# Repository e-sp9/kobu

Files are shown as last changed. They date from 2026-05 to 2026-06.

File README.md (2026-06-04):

# kobu

自作分割キーボード「kobitokey」にインスパイアされて作った派生キーボード「kobu」の KiCad プロジェクトとファームウェアです。親指キーを追加し、メインキー側を 2 キー削っています。

## ディレクトリ構成

| ディレクトリ | 中身 |
|---|---|
| [`pcb/`](pcb/) | KiCad プロジェクト (PCB / 回路図) |
| [`case/`](case/) | ケースの STEP / STL |
| [`firmware/rmk/`](firmware/rmk/) | RMK ベースのファームウェア (Rust, thumbv7em-none-eabihf) |
| [`firmware/zmk/`](firmware/zmk/) | ZMK 版ファームウェア (Zephyr, Nix/flake ビルド) |
| [`web/rmk-editor/`](web/rmk-editor/) | RMK 用 Web キーマップエディタ (WebHID + Vial protocol, React) |
| [`web/zmk-editor/`](web/zmk-editor/) | ZMK 用 Web キーマップエディタ (ZMK Studio over USB/BLE, React) |

## 開発環境

`flake.nix` が toolchain バージョンの単一情報源。CI も同じ devshell で走るので host とドリフトしない。

### direnv ですぐに使う (推奨)

[nix-direnv](https://github.com/nix-community/nix-direnv) を入れていれば `cd` するだけで対応する devshell が自動起動する:

```sh
direnv allow              # 初回のみ
cd ~/git/private/kobu     # → 全部入り devshell (firmware + web)
cd firmware/rmk/              # → firmware-only (Rust + flip-link + probe-rs)
cd web/rmk-editor/        # → web-only      (Node 26 + pnpm; web/zmk-editor も同じ)
```

各ディレクトリの `.envrc` が `flake.nix` の対応する `devShells.*` を `use flake` で読み込む構成。

### 手動で起動する場合

```sh
nix develop               # 全部入り
nix develop .#firmware    # firmware のみ
nix develop .#web         # web のみ
```

## 主要部品

- スイッチ: Kailh Choc V2 ホットスワップ（1.00u）
- ダイオード: SOD-123
- コネクタ: Hirose FH12-10S-0.5SH（FFC/FPC 10 ピン, 0.5mm ピッチ）
- MCU: Seeed XIAO nRF52840 BLE（左右親指ユニットに 1 個ずつ）
- トラックボール: PMW3610 光学センサー（左右親指ユニットに 1 個ずつ、3 線 SPI）

## キーマップ

keymap

## Vial でキーマップを編集する

ブラウザから kobu のキーマップ・マクロ・コンボを動的に編集できます。RMK が公式に提供しているオンライン編集ルートは Vial 互換のみで、**ブラウザ (vial.rocks) からは USB Raw HID 経由**でしか繋がりません。日常的に BLE で使っていても、編集時だけ USB ケーブルを挿す必要があります。

> **補足**: RMK 0.8 のファームウェア自体は BLE でも Vial プロトコルを喋れます ([`BleVialServer`](https://github.com/HaoboGu/rmk/blob/main/rmk/src/ble/host_service/vial.rs) として実装済み)。ただし Web Bluetooth は HID service UUID `0x1812` をブロックリストで除外しているため vial.rocks からは届きません。Linux/Windows の **Vial デスクトップアプリ** であれば BLE 経由で接続できる可能性がありますが、kobu 上での動作確認はまだ取れていません。

### 必要なもの

- データ通信対応の USB-C ケーブル
- Chromium 系ブラウザ（Chrome / Edge / Brave）。WebHID を使うので Safari と Firefox は不可
- central（左半分）に書き込んだ最新ファームウェア

### 接続手順

1. central を USB ケーブルで PC に接続する（peripheral は接続不要 / 接続しても無視される）
2. <https://vial.rocks> を開く
3. "Authorize device" ボタンを押し、ポップアップで `kobu` を選択
4. キーマップ編集タブで変更したいキーをクリック → 新しいキーコードを選択 → 自動保存

### Unlock chord

キーマップ変更を許可するには、物理位置 `(0, 0)` と `(0, 9)` を**同時押し**します。`(row, col)` は `keyboard.toml` の matrix 上の位置で、論理キーコードではありません。kobu の場合これは:

- `(0, 0)` = 左半分 **外側 pinky**（物理 Q キー位置）
- `(0, 9)` = 右半分 **外側 pinky**（物理 P キー位置）

両手の外側 pinky を同時に押す動作は通常のタイピングではまず起きないので、誤操作で Vial が unlock されることはありません。Vial で Q や P のキーコードを別物に置き換えても、unlock chord は matrix 位置で決まっているため変化しません。

### Layer 3 = Bluetooth 操作レイヤー

Layer 3 row 0 には RMK の "user keycode" 経由で BLE 操作系を割り当てています。Vial 上では `customKeycodes` で定義したラベルで表示されます。

| Vial 上のラベル | 内部の user keycode | 動作 |
|---|---|---|
| BT0 | User0 | BLE プロファイル 0 に切り替え |
| BT1 | User1 | BLE プロファイル 1 に切り替え |
| BT2 | User2 | BLE プロファイル 2 に切り替え |
| BT3 | User3 | BLE プロファイル 3 に切り替え |
| Next BT | User4 | 次のプロファイルに切り替え |
| Prev BT | User5 | 前のプロファイルに切り替え |
| Clear BT | User6 | 現在のプロファイルのペアリング情報を消去 |
| Switch Output | User7 | デフォルト出力先を USB / BLE で切り替え |

ラベルと内部 keycode の対応は `ble_profiles_num = 4` に依存します。`keyboard.toml` の `[rmk]` でこの値を変えた場合、`vial.json` 側の `customKeycodes` も同じ並び規則で書き直す必要があります（RMK 0.8 の `src/keyboard.rs::process_user` 参照）。

数字レイヤー（Layer 2）は**右親指・XIAO 直下から 1 つ外**の `LT(2, Space)`（Space タップ / ホールドで Layer 2）、設定レイヤー（Layer 3）は**さらに 1 つ外**の `LT(3, Enter)`（Enter タップ / ホールドで Layer 3）で入ります。Emacs レイヤー（Layer 5）は Win/Linux モード（Layer 1）でのみ、左親指・XIAO 直下から 1 つ外の `LT(5, LGui)` で入ります。

キーマップは [KobitoKey_QWERTY](https://github.com/s-katada/KobitoKey_QWERTY)（ZMK）から 1:1 で移植しています。kobu の親指 PCB は KobitoKey の 3 親指 / 側に対して 4 親指 / 側あるので、KobitoKey にない一番外側の親指 1 個ずつには Backspace を割り当てています。

| 位置（XIAO 直下 → 外側） | 左手親指 | 右手親指 |
|---|---|---|
| XIAO 直下（内側 SW2） | **英数**（Shift ホールド） | **Esc**（Alt ホールド） |
| SW3 | Ctrl | **Space**（数字層ホールド） |
| SW4 | Backspace（Cmd ホールド） | **Enter**（設定層ホールド） |
| 外側 SW5（kobu 拡張） | Backspace | Backspace |

### macOS で電池残量を表示する

central（左半分）は XIAO nRF52840 BLE の内蔵 1MΩ / 510kΩ 電圧分圧 (ratio = 510/1510 ≒ 0.338) から BAT 電圧を ADC（P0_31）で読み取り、標準 BLE Battery Service (UUID `0x180F`) として host に通知します。macOS の Bluetooth メニュー / システム設定では、Apple Magic Keyboard と同じ位置にバッテリー残量がパーセントで表示されます。

最新ファームウェアを central にフラッシュ済みなのに残量が出ない場合は、**ペアリング情報を作り直す**必要があります。古い build で BLE 接続したことがある macOS は、その時点の GATT サービス構成（Battery Service が含まれていない世代）をキャッシュしているため、ファームを更新しただけでは新しい characteristic を読み直しに来ません。

1. システム設定 → Bluetooth で `kobu` の (i) → "このデバイスの登録を解除"
2. central の電源を入れ直す（USB を一度抜き差しするか、左親指の電源スライドスイッチで OFF→ON）
3. macOS が `kobu` を再発見したら接続
4. Bluetooth メニューを開くと残量が表示される

LED が緑＝60% 以上 / 黄＝20〜60% / 赤＝20% 以下を示します（USB 給電中は赤が抑制されて緑に倒れる）。BLE の数値表示は LED と独立した経路で、`firmware/rmk/keyboard.toml` の `[ble]` セクションで `battery_adc_pin = "P0_31"` と分圧比 (`adc_divider_measured = 510`, `adc_divider_total = 1510`) を設定しています。XIAO nRF52840 BLE の BAT 分圧は対称な 1M/1M ではなく **R10 = 1MΩ / R11 = 510kΩ の非対称** で、`ratio = R11 / (R10 + R11) = 0.338` です。1/2 にしてしまうと健全な 4.0V LiPo が 2.7V と decode され、`get_battery_percent` が 0% を返してしまうので注意。

### 工場リセット

書き換えたキーマップを丸ごと捨ててビルド時の keymap に戻したいときは:

1. `firmware/rmk/keyboard.toml` の `[storage]` で `clear_layout = true` に変更
2. central をフラッシュ
3. 起動後に `clear_layout = false` に戻し、再度フラッシュ

BLE ペアリング情報も含めて全部消したいときは `clear_storage = true` を使います。

### 既知の制約

- **vial.rocks (Web Bluetooth) からは BLE 経由で繋げない**。HID service が Web Bluetooth のブロックリストにあるため。ブラウザ編集は USB ケーブル必須。
- **Vial デスクトップアプリ + BLE での編集は未検証**。RMK 0.8 の `BleVialServer` は実装されているので Linux/Windows の Vial 経由なら届く可能性あり。動いた人がいたら issue 起票歓迎。
- **peripheral 側（右半分）は USB に挿しても Vial で認識されない**。Vial 通信は central だけが処理します。
- 完全な Web 経由 (Web Bluetooth or WebUSB) 編集は RMK upstream の独自プロトコル ([HaoboGu/rmk#558](https://github.com/HaoboGu/rmk/issues/558)) 完成待ち。

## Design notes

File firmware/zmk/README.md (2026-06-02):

# kobu — ZMK firmware

A ZMK port of kobu's firmware. The original RMK firmware is preserved in
[`../rmk/`](../rmk) (`firmware/rmk/`); this directory is the ZMK config. The
build is driven by the single repo-root [`flake.nix`](../../flake.nix) (via
`zmk-nix`), so **no west / Zephyr / SDK install is required**. `cd`-ing here
activates the `zmk` dev shell through [`.envrc`](.envrc).

The keymap, trackball behavior, BLE tuning and RGB-LED status are ported 1:1
from the RMK firmware (`../rmk/keyboard.toml`, `../rmk/src/*.rs`), which itself derives
from [KobitoKey_QWERTY](https://github.com/s-katada/KobitoKey_QWERTY) (ZMK).
kobu is a different PCB, so the matrix pins, the `row2col` diode direction and
the dual-trackball wiring are kobu-specific (see `config/boards/shields/kobu/`).

## Layout

```
firmware/zmk/
  .envrc                          # `use flake "path:../..#zmk"` (build shell)
  build.yaml                      # GitHub Actions matrix (CI parity; not used by Nix)
  config/
    west.yml                      # pins ZMK v0.3 + PMW3610 driver + rgbled-widget
    kobu.keymap                   # 7 layers, combos, behaviors (1:1 from RMK)
    boards/shields/kobu/
      kobu.dtsi                   # 4x10 matrix (row2col), split inputs, layout
      kobu_left.overlay           # central: SPI + left ball (scroll) + auto-mouse
      kobu_right.overlay          # peripheral: col override + right ball (pointer)
      kobu_left.conf / kobu_right.conf
      Kconfig.shield / Kconfig.defconfig
      kobu.zmk.yml
```

LEFT = central (local trackball → scroll). RIGHT = peripheral (trackball
forwarded over the split link → pointer + auto-mouse layer 4).

## Build (Nix)

The ZMK build is exposed by the repo-root flake (`packages.zmk*`), with
`zephyrDepsHash` already pinned, so a clean build just works (verified building
both halves + the reset image). Run from the **repo root**:

```sh
# Both halves + reset, named for kobu -> result/kobu_{left,right,reset}.uf2
nix build .#zmk-bundle
cp -L result/kobu_left.uf2  ./kobu_left.uf2
cp -L result/kobu_right.uf2 ./kobu_right.uf2
cp -L result/kobu_reset.uf2 ./kobu_reset.uf2

# Or just the two halves:  nix build .#zmk   -> result/zmk_{left,right}.uf2
# Or just the reset image: nix build .#zmk-reset
```

> Files must be tracked by git for the flake to see them (`git add firmware/zmk`).

If `firmware/zmk/config/west.yml` ever changes (ZMK / module revisions),
re-bootstrap the hash: set `zmkDepsHash = lib.fakeHash;` in the root `flake.nix`,
run `nix build .#zmk`, and paste the reported `got: sha256-...` back in.

## Flash

Double-tap the XIAO reset button; it mounts as a USB mass-storage volume. Copy
the matching UF2 onto it:

```sh
cp kobu_left.uf2  /Volumes/XIAO-SENSE/     # central / left half
cp kobu_right.uf2 /Volumes/XIAO-SENSE/     # peripheral / right half
```

`kobu_reset.uf2` clears BLE bonds + stored settings (flash it, then reflash the
normal half firmware).

## Fallback: manual west build

If you prefer raw west, the root flake's `zmk` dev shell provides the full
toolchain (auto-activated here via `.envrc`, or `nix develop .#zmk` from the
repo root):

```sh
cd firmware/zmk          # .envrc activates the zmk shell (or: nix develop ../..#zmk)
west init -l config
west update
west build -p -d build/left  -s zmk/app -b seeeduino_xiao_ble \
  -S studio-rpc-usb-uart \
  -- -DSHIELD="kobu_left rgbled_adapter" -DZMK_CONFIG="$PWD/config" -DZMK_EXTRA_MODULES="$PWD/config"
west build -p -d build/right -s zmk/app -b seeeduino_xiao_ble \
  -- -DSHIELD="kobu_right rgbled_adapter" -DZMK_CONFIG="$PWD/config" -DZMK_EXTRA_MODULES="$PWD/config"
cp -L build/left/zephyr/zmk.uf2  ../../kobu_left.uf2
cp -L build/right/zephyr/zmk.uf2 ../../kobu_right.uf2
```

## Keymap editing

ZMK Studio (over USB, central only) replaces kobu's RMK Vial/web editor.
`CONFIG_ZMK_STUDIO=y` is set on the central; connect at <https://zmk.studio>.

## Differences from the RMK firmware (faithful-port notes)

- Trackball **direction flags** (scroll roll-right = up; pointer Y-invert)
  depend on physical ball mounting — RMK exposes them as runtime flags. The ZMK
  defaults here match RMK's defaults; if scroll/pointer goes the wrong way on
  the bench, flip `INPUT_TRANSFORM_*` in the overlays (see comments).
- The RMK auto-mouse "travel gate" / sub-count keepalive are approximated by
  ZMK's `zip_temp_layer` (activate on motion after 300 ms prior-idle, 150 ms
  idle-deactivate); behavior is equivalent for normal use.
- RGB LED uses `zmk-rgbled-widget` (battery boot color + per-layer colors +
  connection status) instead of RMK's bespoke controller; layer colors match
  `../rmk/src/status_led.rs`.

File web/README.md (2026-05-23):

# kobu-config (web app)

Web-based keymap editor for the [kobu](../) split keyboard, served as a
single-page app. Talks to kobu's central half over USB or BLE-HoG via
the WebHID API and the Vial wire protocol — no native install, no
driver required.

Lives inside the kobu monorepo. Firmware at [`../firmware/`](../firmware/),
hardware at [`../pcb/`](../pcb/).

## What you can do with it

| Feature | Status |
|---|---|
| Read / write keymap (4 layers × 4×10 matrix) | ✅ |
| Categorised keycode picker (basic / mods / layers / mouse / media / kobu-specific BT keys) | ✅ |
| Layer 3 dedicated BLE-profile panel | ✅ |
| Macros (Vial advanced format — tap / press / release / delay) | ✅ |
| Combos (up to 4 input keys → 1 output key, ×16 slots) | ✅ |
| Tap-dance (tap / hold / double-tap / hold-after-tap + per-entry tap-term) | ✅ |
| Firmware install from latest GitHub Release (UF2 + clean install) | ✅ |
| PWA / offline support (install as an app, works without network) | ✅ |
| Unsupported-browser splash with download recommendations | ✅ |
| Trackball / scroll / LED tuning panel | 🚧 see #39, #40 |

## Browser support

WebHID is Chromium-only:

| Platform | Supported browsers |
|---|---|
| Desktop (macOS / Windows / Linux) | Chrome, Edge, Brave, Opera, Vivaldi |
| Android | Chrome (USB-OTG cable required for kobu) |
| iOS | ❌ — all iOS browsers use WebKit; no WebHID |
| Safari (any version) | ❌ |
| Firefox (any version) | ❌ |

The app detects the environment on load and shows a dedicated splash
explaining what to install if WebHID is missing.

## User guide

### First-time setup

1. Connect kobu's **central half** (left half) to your computer with a
   data-capable USB-C cable. The peripheral half does not need to be
   connected.
2. Open the kobu-config URL in Chrome (or another Chromium browser).
3. Click **「kobu に接続」** ("Connect to kobu"). The browser pops up a
   device-picker — select kobu and click *Connect*.
4. The editor loads your current keymap from the device.

> **BLE editing works too**: once kobu is paired in your OS Bluetooth
> settings, Chrome's WebHID picker on macOS / Android / some Linux
> distros surfaces the BLE-paired kobu just like a USB device. Windows
> often requires USB because its HID stack doesn't always expose BLE
> HID devices.

### Editing keys

1. Click a key on the SVG matrix.
2. Pick a new keycode from the picker (search box + categorised tabs).
3. Click **「保存」** ("Save"). The editor will only persist if the
   firmware is **unlocked** (see below).
4. The amber dot on the layer tab fades as the firmware confirms each
   write.

### Unlocking the firmware

Vial firmwares ship locked — you have to physically hold a key
**chord** to prove you have the keyboard in front of you before
writes are accepted. For kobu the chord is the **two outermost pinky
keys** (`row 0, col 0` and `row 0, col 9` in the matrix — the Q and P
positions on a default QWERTY layout).

If you ever remap those positions to other keycodes, the chord is
still the *matrix* position, not the logical key — the unlock is
unaffected.

### Macros / combos / tap-dance

Scroll past the keymap section to find dedicated panels for each. All
three open the same keycode picker for individual fields, so the
familiar shortcuts apply.

### Firmware install

The **「ファームウェア」** section at the bottom of the page fetches
the latest UF2 from the kobu GitHub release and writes it via the
File System Access API (also Chromium-only). Two flows:

- **通常インストール** — overlay the new firmware; keeps your existing
  keymap.
- **クリーンインストール** — also resets the saved keymap to the
  firmware's build-time default. Useful when migrating between
  firmware versions that change the matrix shape.

Both flows do *not* touch BLE pairings.

## FAQ

**Q. Safari で動きません.**
A. WebHID API がないので動きません。Chromium 系（Chrome / Edge /
Brave / Opera）をインストールしてください。iOS の Chrome も実は
WebKit エンジンなので動きません — 別のデバイスを使ってください。

**Q. kobu に接続を押しても何も出てきません.**
A. データ通信非対応の USB ケーブル（充電専用ケーブル）の可能性が
あります。データ対応ケーブルに差し替えて再試行してください。

**Q. デバイスは選択できるけど "デバイスがロックされています" と出ます.**
A. 物理 unlock chord（両外側 pinky 同時押し）が必要です。`(0, 0)` と
`(0, 9)` の matrix 位置を同時に押し、押したまま「保存」してください。
詳細はリポジトリ root の [README.md](../README.md#unlock-chord) を
参照。

**Q. BLE 経由で繋がりません.**
A. macOS / Android / 一部 Linux なら、OS Bluetooth 設定で kobu を
ペアリング済みなら Chrome の WebHID ピッカーに出ます。Windows の HID
スタックは BLE HID デバイスを surface しないことが多く、その場合は
USB ケーブルで接続してください。

**Q. インストールしたのに次回も「初回ロード中」と出ます.**
A. PWA としてインストールしてもブラウザがキャッシュを別途消すと再
ロードが走ります。ホーム画面アイコンから開いてもキャッシュが消えて
いれば最初の HTML/JS フェッチだけは必要です。

**Q. 設定をやり直したい.**
A. ヘッダー右の "切断" を押し、もう一度接続すると最新の状態を読み
直します。完全に出荷状態に戻したい場合は firmware section の
"Reset" を使うか、`keyboard.toml` の `clear_layout = true` で再
フラッシュしてください（BLE ペアリングごと消すなら `clear_storage`）。

## Develop

The kobu nix devshell provides Node and pnpm — the same versions CI
uses. Enter it from the **repo root** (one level up from this
directory) or rely on direnv if you have nix-direnv installed:

```sh
nix develop                # at the kobu repo root, or
cd web && nix develop ..#web

pnpm install               # one-time
pnpm dev                   # http://localhost:5173
pnpm test                  # vitest
pnpm lint                  # biome
pnpm typecheck             # tsc -b --noEmit
pnpm build                 # production bundle in dist/
```

`flake.nix` pins Node 26 and pnpm. Bumping the Node major is a
one-line change in `../flake.nix` and CI picks it up automatically —
local dev and CI cannot drift.

### Cloudflare Workers (production hosting)

The SPA ships as a Cloudflare Worker that serves the Vite-built
`dist/` directory plus a `/__release` proxy to GitHub (so the
firmware-install flow can download UF2 binaries without CORS pain).
Locally:

```sh
pnpm cf:dev      # wrangler dev
pnpm cf:deploy   # build + wrangler deploy   (needs API token)
pnpm cf:tail     # tail production logs
```

CI deploys to production automatically on every push to `main` once
the lint / typecheck / test / build steps succeed. This requires two
**repository secrets** in GitHub:

- `CLOUDFLARE_API_TOKEN` — token scoped to *Edit Workers Scripts* +
  *Account → Workers KV Storage*.
- `CLOUDFLARE_ACCOUNT_ID` — your CF account id (visible in the
  dashboard URL).

The Worker also attaches a strict Content-Security-Policy and a
`Permissions-Policy` that grants `hid` only to our origin. The
`/__release` proxy keeps GitHub's response headers unmodified.

## Architecture (high-level)

```
        ┌────────────────────────────────────────────────────┐
  App ──┤  React 19 + Tailwind 4 + Zustand 5                 │
        │  ─────────────────────────────────────────────     │
        │  ConnectButton    KeymapView      KeycodePicker    │
        │  EditorToolbar    MacroEditor     ComboEditor      │
        │  MorseEditor      BluetoothPanel  FirmwareSection  │
        │  PwaUpdateToast   UnsupportedBrowserSplash         │
        └───────────────┬────────────────────────────────────┘
                        │
                        ▼  state/
        ┌────────────────────────────────────────────────────┐
        │  connection · editor · macros · combos · morses    │
        │  firmware                                          │
        └───────────────┬────────────────────────────────────┘
                        │
                        ▼  protocol/
        ┌────────────────────────────────────────────────────┐
        │  handshake · keymap · macros · combos · morses     │
        │  unlock · cache · commands (32-byte Vial packets)  │
        └───────────────┬────────────────────────────────────┘
                        │
                        ▼  transport/
        ┌────────────────────────────────────────────────────┐
        │  WebHidTransport (navigator.hid + ViaReport HID    │
        │                   collection 0xFF60/0x61)          │
        └────────────────────────────────────────────────────┘
                        │
                        ▼
                     ┌──────┐
                     │ kobu │  RMK 0.8 firmware
                     └──────┘
```

Decisions log: [#21](https://github.com/s-katada/kobu/issues/21).
Roadmap meta: [#41](https://github.com/s-katada/kobu/issues/41).

## Tech stack

- React 19 + TypeScript (strict, `noUncheckedIndexedAccess`,
  `exactOptionalPropertyTypes`)
- Vite 8 + Rolldown (build / dev server)
- Tailwind CSS 4 (utility styling)
- Zustand 5 (state management)
- Biome 2 (lint + format)
- Vitest 4 (unit + component tests, jsdom)
- vite-plugin-pwa + workbox (offline support)
- Cloudflare Workers + wrangler (production hosting)

## License

GPL-2.0-or-later — chosen pre-emptively to allow borrowing
protocol-layer code from upstream Vial projects. Will revisit if it
turns out we wrote the protocol layer from scratch.

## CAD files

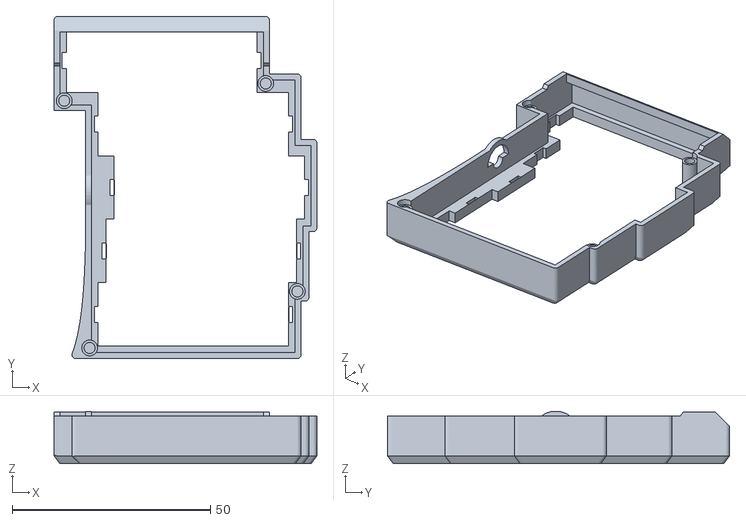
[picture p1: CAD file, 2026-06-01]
case/stl/main-unit/main-side-plate.stl
66.3 x 86.3 x 13.2

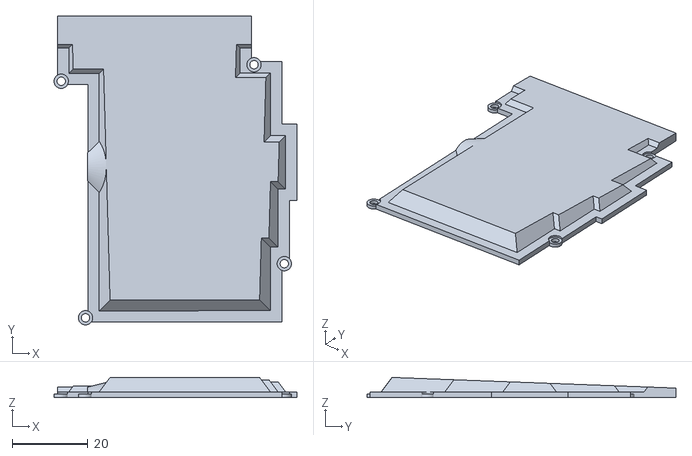
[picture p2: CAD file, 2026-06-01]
case/stl/main-unit/main-bottom-plate.stl
64.0 x 81.4 x 5.31

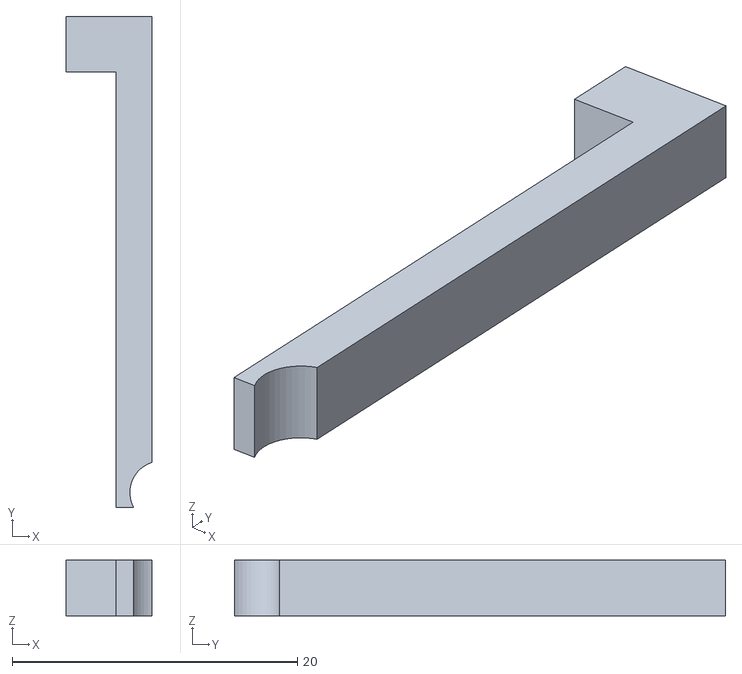
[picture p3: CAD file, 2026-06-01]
case/stl/main-unit/main-unit-right-spacer-bottom2.stl
6.00 x 34.4 x 3.90

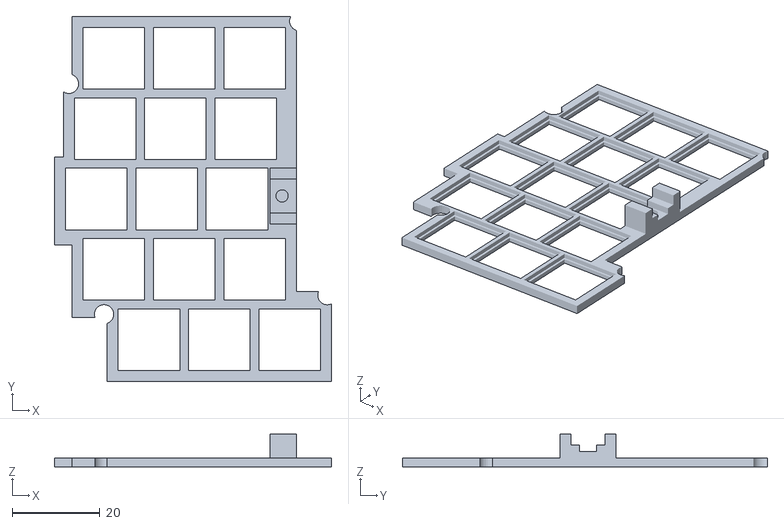
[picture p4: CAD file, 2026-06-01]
case/stl/main-unit/main-top-plate.stl
63.0 x 83.0 x 7.50

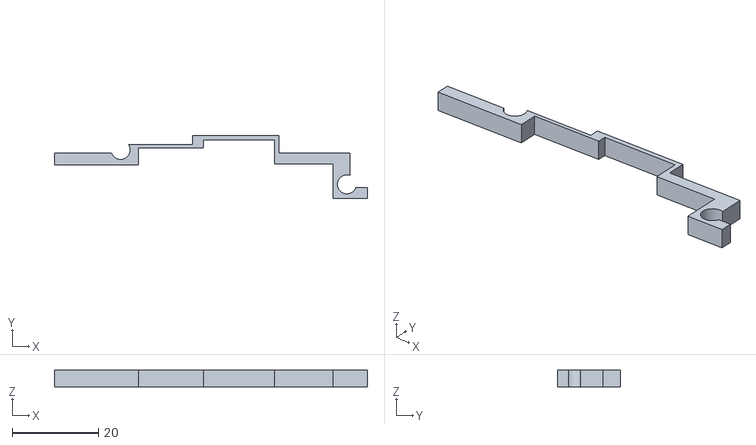
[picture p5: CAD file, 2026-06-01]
case/stl/main-unit/main-unit-right-spacer-top.stl
72.5 x 14.5 x 3.90

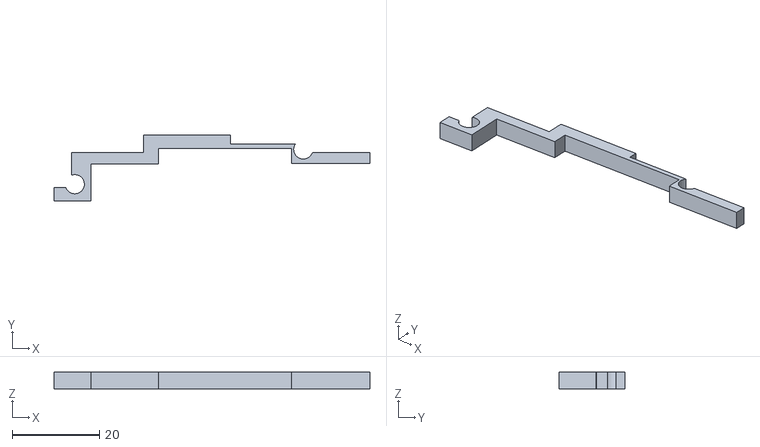
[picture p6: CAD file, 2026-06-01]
case/stl/main-unit/main-unit-left-spacer-top.stl
72.5 x 15.1 x 3.90

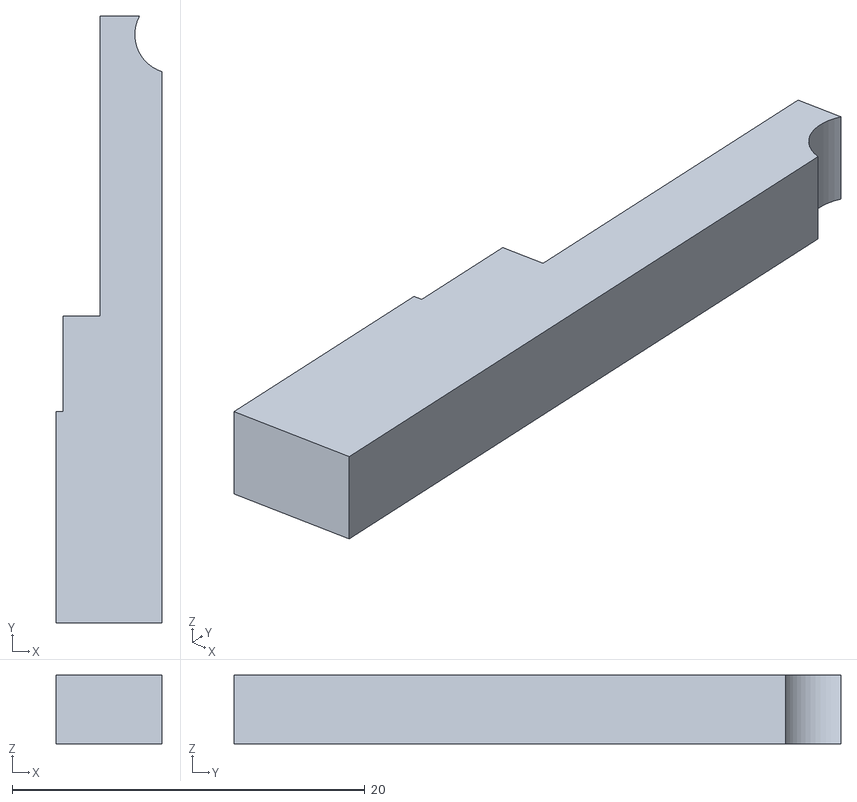
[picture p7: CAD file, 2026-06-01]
case/stl/main-unit/main-unit-left-spacer-bottom1.stl
6.00 x 34.4 x 3.90

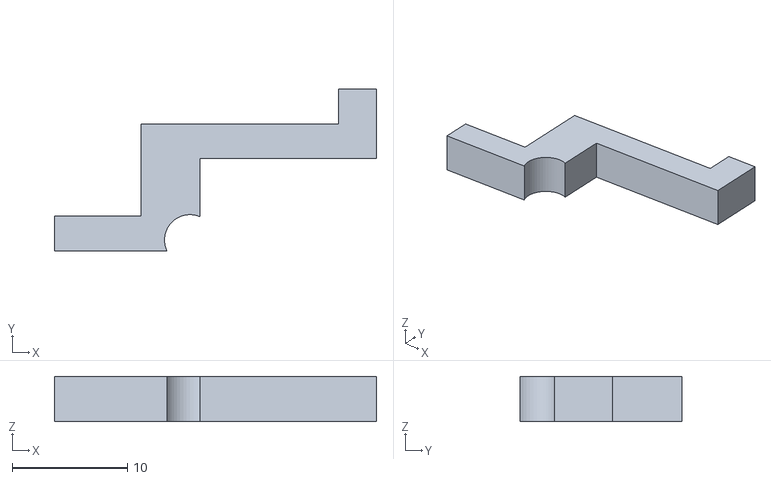
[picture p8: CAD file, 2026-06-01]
case/stl/main-unit/main-unit-left-spacer-bottom2.stl
27.9 x 14.0 x 3.90

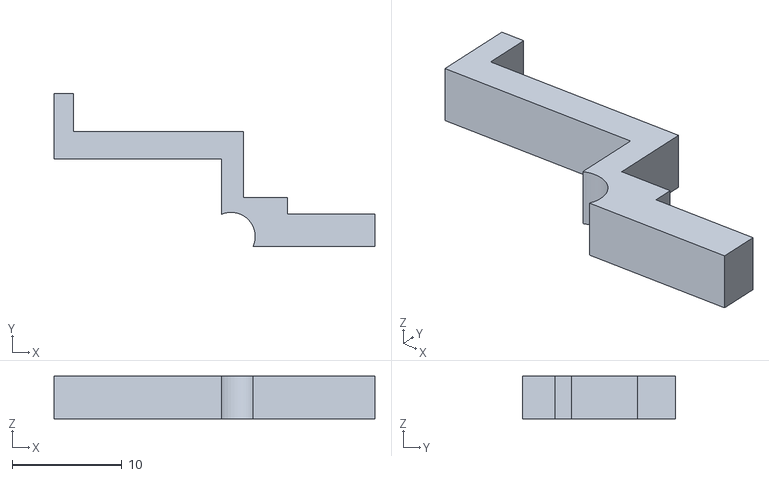
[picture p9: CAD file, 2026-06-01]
case/stl/main-unit/main-unit-right-spacer-bottom1.stl
29.3 x 14.0 x 3.90

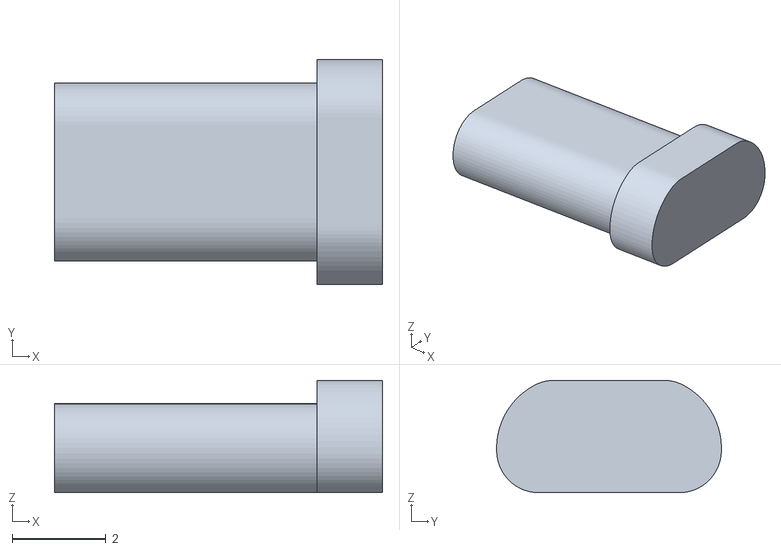
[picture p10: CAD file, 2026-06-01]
case/stl/common/reset-button.stl
7.00 x 4.80 x 2.40

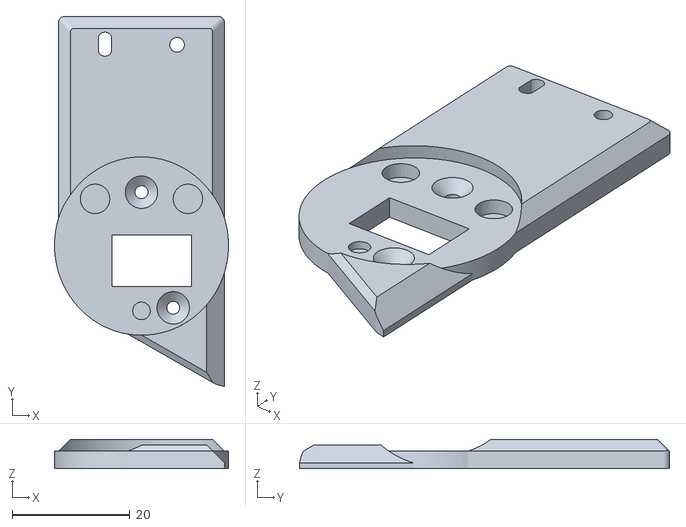
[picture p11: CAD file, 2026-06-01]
case/stl/thumb/xiao-cover-left.stl
29.5 x 62.7 x 5.00

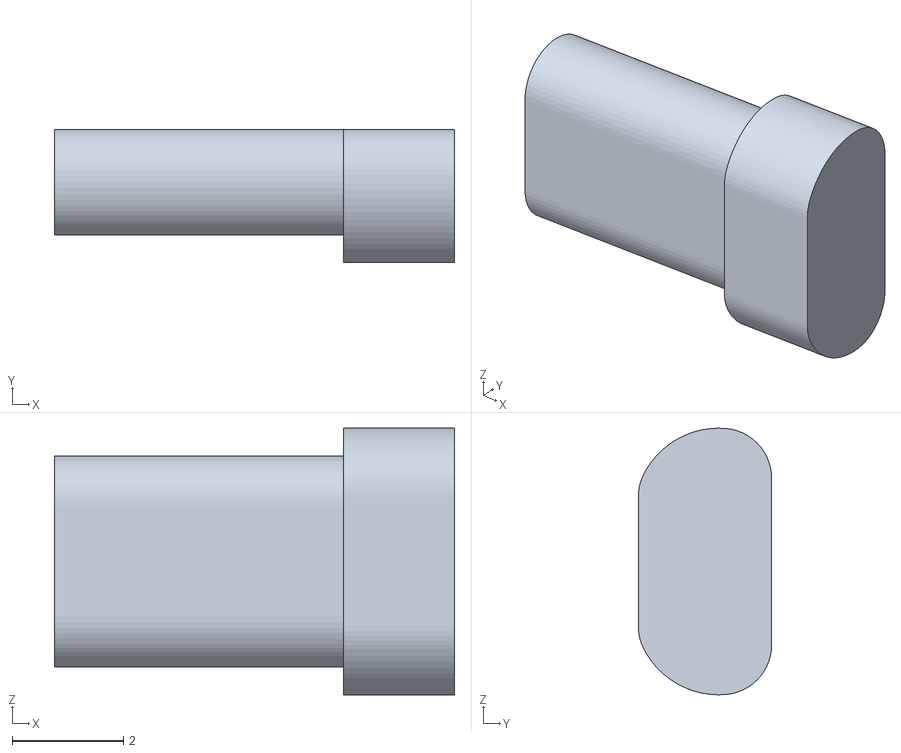
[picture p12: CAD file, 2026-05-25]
case/thumb/reset-button.stl
7.20 x 2.40 x 4.80

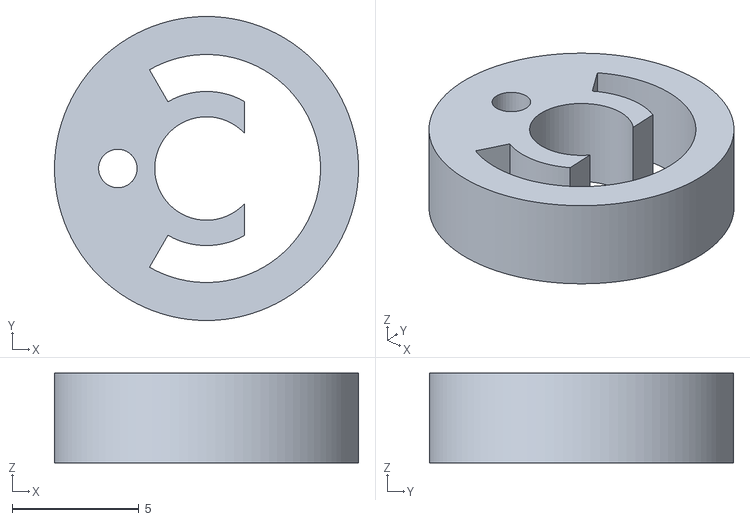
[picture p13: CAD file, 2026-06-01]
case/stl/common/hinji-cover.stl
12.0 x 12.0 x 3.55

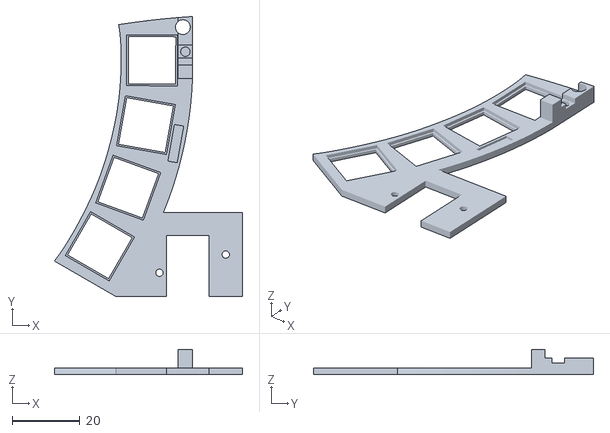
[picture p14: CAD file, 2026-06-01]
case/stl/thumb/thumb-top-plate.stl
55.7 x 82.8 x 7.50

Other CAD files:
case/thumb-bottom-plate.stl
case/thumb/xiao-cover.stl
case/stl/common/power-switch.stl
case/stl/thumb/thumb-bottom-plate.stl
case/main-bottom-plate.stl
case/main-side-plate.stl
case/main-unit-left-spacer-bottom1.stl
case/main-unit-left-spacer-bottom2.stl
case/main-unit-left-spacer-top.stl
case/main-unit-right-spacer-bottom1.stl
case/main-unit-right-spacer-bottom2.stl
case/main-unit-right-spacer-top.stl
case/stl/thumb/thumb-side-plate.stl
case/stl/thumb/track-ball-case.stl
case/stl/thumb/xiao-cover-right.stl
case/thumb-side-plate.stl
case/thumb/thumb-bottom-plate.stl
case/thumb/thumb-side-plate.stl

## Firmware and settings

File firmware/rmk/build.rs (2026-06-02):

use const_gen::*;
use std::fs::File;
use std::io::{Read, Write};
use std::path::{Path, PathBuf};
use std::{env, fs};
use xz2::read::XzEncoder;

fn main() {
    println!("cargo:rerun-if-changed=vial.json");
    println!("cargo:rerun-if-changed=keyboard.toml");

    patch_rmk_ble_for_macos();
    patch_rmk_battery_service();
    patch_rmk_battery_processor_signal();
    patch_rmk_battery_kobu_atomics();
    patch_rmk_kobu_settings_atomics();
    patch_rmk_via_custom_get_kobu();
    // NOTE: peripheral_bootloader_jump must run BEFORE via_custom_set_kobu_settings:
    // the latter anchors on the CustomSetValue arm AFTER the bootloader-jump patch
    // has rewritten the upstream stub. (Order only matters on a pristine registry —
    // e.g. a clean cargo cache or CI — because the patches are marker-idempotent.)
    patch_rmk_peripheral_bootloader_jump();
    patch_rmk_via_custom_set_kobu_settings();
    patch_rmk_via_custom_save_kobu();
    patch_rmk_macro_adc_acquisition_time();
    patch_rmk_host_advertise_fast();
    patch_rmk_split_peripheral_advertise_fast();
    patch_rmk_split_peripheral_wake_on_pointer();
    patch_rmk_split_peripheral_publish_battery();
    patch_rmk_split_peripheral_decode_battery_while_advertising();
    patch_rmk_conn_params_fast_settling();
    patch_rmk_host_conn_low_latency();
    patch_rmk_split_conn_low_latency();
    patch_rmk_split_state_resync_fast();
    patch_rmk_force_ble_conn_type();
    patch_rmk_force_hid_cccd_on_connect();
    patch_rmk_gate_ble_writer_on_encrypted();
    patch_rmk_timeout_ble_writer();
    patch_rmk_request_security_on_connect();
    patch_rmk_keymap_layer_pub();
    patch_rmk_last_key_tick_atomic();
    patch_rmk_record_last_key_tick();
    // Round 7 — boot-trackball BLE wedge + mouse-drag/copy. These add NEW
    // atomics and NEW rmk patches, so a `cargo clean --release -p rmk` is
    // required once after pulling this change (see the buildrs-patch-recompile
    // note in project memory). The atomics injection MUST run before the
    // patches that reference the atomics by path are compiled, but ordering
    // among build.rs functions only matters for anchor availability — so the
    // atomics patch anchors on the last-key-tick atomic injected just above.
    patch_rmk_kobu_wedge_drag_atomics();
    patch_rmk_set_host_connected();
    patch_rmk_timeout_split_writes();
    patch_rmk_capture_mouse_buttons();
    patch_rmk_pmw3610_slower_poll();
    // Round 8 — the boot-trackball wedge (R1–R7 all failed). Root cause: the
    // peripheral forwards every pointer sample over the split link with an
    // UNBOUNDED blocking write (split/peripheral.rs), flooding the central's
    // single shared trouBLE RX pool during the Mac SMP/encryption window and
    // silently dropping the encryption PDU → "connected but dead until a
    // supervision-timeout reconnect." Fix: bound that forward (Layer A) AND gate
    // the whole PMW3610 pipeline on BOTH halves until the host link is READY
    // (BLE-encrypted OR USB) — Layer B. Adds new atomics + a new SplitMessage
    // variant; REQUIRES `cargo clean --release -p rmk` (registry-patch gotcha).
    patch_rmk_kobu_input_gate_atomics();
    patch_rmk_timeout_peripheral_event_write();
    patch_rmk_pmw3610_input_gate();
    patch_rmk_split_host_ready_variant();
    patch_rmk_emit_host_ready();
    patch_rmk_peripheral_apply_host_ready();
    // Round 10 — the wedge is a HANG (not reset) on the BONDED-RECONNECT-while-
    // Mac-holds-a-STALE-link path + trackball motion. On a stale resume the Mac
    // re-encrypts from the stored LTK and fires a dense GATT cache-revalidation
    // burst; kobu opened the trackball gate on the first encrypted GATT read
    // (R8), i.e. straight into that burst, BEFORE host TX credits were flowing —
    // the ~500Hz pointer flood then starved the single shared trouBLE TX queue +
    // 16-packet pool, the lone TxRunner parked on a host PDU, and the UNBOUNDED
    // `reply.send().await` in gatt_events_task deadlocked. Layer A bounds that
    // await; Layer C shrinks the stale window (5s->2s) like ZMK/KobitoKey.
    // (Layer B = a 2s post-encryption settle in run_input_gate_central, firmware;
    //  Layer D = bigger trouBLE pool via .cargo/config.toml env.)
    patch_rmk_timeout_gatt_reply();
    patch_rmk_supervision_timeout_2s();
    // Pointer "もっさり over time": macOS relaxes the bonded HID link to a slow
    // interval (~30-50ms) for power-saving after a while; rmk only logs the
    // change, so the pointer report rate drifts to ~20-33Hz and STAYS there
    // until reconnect. Capture the live interval and re-assert the fast 7.5ms
    // params, but only when actually drifted slow (don't spam macOS).
    patch_rmk_host_conn_interval_atomic();
    patch_rmk_reassert_fast_conn_params();
    // Round 12: make the round-11 re-assert EVENT-DRIVEN. After a motion-heavy
    // stale reconnect macOS lands the link fully relaxed (~30-50ms); the 10s
    // poll then took up to ~10s to pull it back to 7.5ms = the acute "もっさり→
    // しばらくで回復". Signal the re-assert loop the instant a slow interval lands
    // (in the ConnectionParamsUpdated arm) + keep a 2s backstop, collapsing the
    // recovery from ~10s to ms. Anchors on the round-11 patched text → run after.
    patch_rmk_conn_drift_atomic();
    patch_rmk_conn_drift_event_driven();
    // Round 18 — pointer もっさり OVER TIME = the macOS host link relaxes over a
    // session. kobu's stage-2 request was a FIXED min==max=7.5ms, BELOW Apple's
    // ~11.25ms BLE-HID floor → macOS SILENTLY REJECTS it → the link sits at
    // stage-1's fixed 15ms (66Hz, never the 7.5ms/133Hz ZMK reaches) and over
    // time relaxes into the 15-18ms band that the >18ms re-assert gate never
    // corrects. ZMK requests a RANGE 7.5-15ms (MIN_INT=6/MAX_INT=12) which macOS
    // CAN satisfy near its floor and HOLDS all session. This patch makes kobu
    // ZMK-faithful: stage-2 → range 7.5-15ms, re-assert → range 7.5-15ms, both
    // drift gates 18ms→12ms (close the dead band; matches the "past 12ms"
    // comment). ADDITIVE — anchors on the reassert/conn-drift patched text, so
    // it MUST run after them. Host-only + request-not-force → no wedge risk.
    patch_rmk_host_conn_range_zmk();
    // Round 19 — residual over-time excursions: macOS grants the MAX end of the
    // requested range, so round-18's [7.5,15ms] rested at 15ms (66Hz) and 15ms
    // ALSO tripped the >12ms gate (self-sustained re-assert churn that re-opens
    // negotiation → macOS re-grants the slow end). ZMK requests its range ONCE
    // and never perturbs it. Cap MAX at the 11.25ms Apple HID floor (rest
    // 89-133Hz) + raise the gate 12ms→13ms so the healthy point stops re-tripping
    // (a true relax ≥30ms still fires). ADDITIVE on the round-18 output → after.
    patch_rmk_host_conn_narrow_max_r19();
    // Round 21 — pointer のろのろ ROOT CAUSE (LED-confirmed: PURPLE ~15ms during
    // のろのろ, no white): peripheral LATENCY, not interval. kobu requested
    // max_latency=0 at every host conn-param site; ZMK requests latency=30.
    // latency=0 forbids macOS the cheap power-save (skip idle intervals), so its
    // ONLY lever is to RELAX THE INTERVAL (~15ms=66Hz=のろのろ); the 2s re-assert
    // then claws it back = the ~5s relax/recover loop. latency=30 keeps the fast
    // interval and lets macOS skip idle events instead (ZMK behaviour). Host conn
    // only (the split link in split/ble/central.rs stays latency 0 — low relay
    // lag). Active input is instant (latency applies only when idle).
    patch_rmk_host_latency_30_r21();
    // Round 23 diagnostic — count pointer samples PRODUCED by the PMW3610 (in
    // read_event) so the PERIPHERAL LED can show its own production rate. The
    // central LED already shows the ARRIVAL rate; comparing the two decisively
    // separates "right sensor produces too few" (production) from "split link
    // loses them in transit". Two additive patches (atomic + increment).
    patch_rmk_peripheral_samples_atomic_r23();
    patch_rmk_peripheral_samples_count_r23();
    // Round 24 — のろのろ ROOT CAUSE (confirmed: both diag LEDs green during のろのろ
    // ⇒ samples reach the central fine; host link is the issue; "~5s recovery" =
    // kobu's 2s re-assert cycle). kobu RE-ASSERTS host conn-params every 2s
    // (churn), which re-opens negotiation and makes macOS RELAX the link →
    // のろのろ → re-assert claws back in ~5s → relaxes again. KobitoKey requests
    // host params ONCE ([7.5,15ms], latency 0, sup 2s) and never touches them, so
    // macOS HOLDS the link = smooth. Make kobu KobitoKey-exact + REQUEST-ONCE:
    // latency 30→0, max 11.25→15ms ([7.5,15] range macOS accepts & holds), and
    // neuter both re-assert gates (>13ms → >4s = never fires) so no churn.
    patch_rmk_host_conn_request_once_r24();

    generate_vial_config();

    let out = &PathBuf::from(env::var_os("OUT_DIR").unwrap());
    File::create(out.join("memory.x"))
        .unwrap()
        .write_all(include_bytes!("memory.x"))
        .unwrap();
    println!("cargo:rustc-link-search={}", out.display());

    println!("cargo:rerun-if-changed=memory.x");

    println!("cargo:rustc-link-arg=--nmagic");
    println!("cargo:rustc-link-arg=-Tlink.x");
    println!("cargo:rustc-link-arg=-Tdefmt.x");

    println!("cargo:rustc-linker=flip-link");
}

fn generate_vial_config() {
    let out_file = Path::new(&env::var_os("OUT_DIR").unwrap()).join("config_generated.rs");

    let p = Path::new("vial.json");
    let mut content = String::new();
    match File::open(p) {
        Ok(mut file) => {
            file.read_to_string(&mut content)
                .expect("Cannot read vial.json");
        }
        Err(e) => println!("Cannot find vial.json {:?}: {}", p, e),
    };

    let vial_cfg = json::stringify(json::parse(&content).unwrap());
    let mut keyboard_def_compressed: Vec<u8> = Vec::new();
    XzEncoder::new(vial_cfg.as_bytes(), 6)
        .read_to_end(&mut keyboard_def_compressed)
        .unwrap();

    let keyboard_id: Vec<u8> = vec![0xB9, 0xBC, 0x09, 0xB2, 0x9D, 0x37, 0x4C, 0xEA];
    let const_declarations = [
        const_declaration!(pub VIAL_KEYBOARD_DEF = keyboard_def_compressed),
        const_declaration!(pub VIAL_KEYBOARD_ID = keyboard_id),
    ]
    .map(|s| "#[allow(clippy::redundant_static_lifetimes)]\n".to_owned() + s.as_str())
    .join("\n");
    fs::write(out_file, const_declarations).unwrap();
}

/// Apply small, idempotent patches to the crates.io `rmk` 0.8.2 sources.
///
/// 1. Advertise on LE 1M PHY — macOS Bluetooth settings often ignore peripherals
///    that only advertise on LE 2M (RMK hard-codes 2M in `advertise()`).
/// 2. Default to BLE-priority when no connection preference is stored — RMK 0.8
///    otherwise defaults to USB, which suppresses BLE discovery while USB is
///    attached (HaoboGu/rmk#157, #159).
fn patch_rmk_ble_for_macos() {
    const MARKER: &str = "// kobu: macOS BLE patches applied";
    const RMK_VERSION: &str = "0.8.2";

    let Some(path) = find_rmk_ble_mod(RMK_VERSION) else {
        println!(
            "cargo:warning=kobu: could not find rmk-{RMK_VERSION} in the cargo registry; \
             macOS BLE patches were not applied"
        );
        return;
    };

    println!("cargo:rerun-if-changed={}", path.display());

    let mut contents = fs::read_to_string(&path).unwrap_or_else(|e| {
        panic!("kobu: failed to read {}: {e}", path.display());
    });

    if contents.contains(MARKER) {
        return;
    }

    let replacements = [
        (
            "primary_phy: PhyKind::Le2M,\n        secondary_phy: PhyKind::Le2M,",
            "primary_phy: PhyKind::Le1M,\n        secondary_phy: PhyKind::Le1M,",
        ),
        (
            "CONNECTION_TYPE.store(ConnectionType::Usb.into(), Ordering::SeqCst);",
            "CONNECTION_TYPE.store(ConnectionType::Ble.into(), Ordering::SeqCst);",
        ),
    ];

    for (from, to) in replacements {
        if !contents.contains(from) {
            panic!(
                "kobu: expected rmk-{RMK_VERSION} source fragment missing in {}; \
                 upstream may have changed — update firmware/build.rs",
                path.display()
            );
        }
        contents = contents.replace(from, to);
    }

    contents.push('\n');
    contents.push_str(MARKER);
    contents.push('\n');

    fs::write(&path, contents).unwrap_or_else(|e| {
        panic!("kobu: failed to write {}: {e}", path.display());
    });
}

fn find_rmk_ble_mod(rmk_version: &str) -> Option<PathBuf> {
    find_rmk_file(rmk_version, "src/ble/mod.rs")
}

fn find_rmk_file(rmk_version: &str, rel_path: &str) -> Option<PathBuf> {
    let home = env::var("HOME")
        .or_else(|_| env::var("USERPROFILE"))
        .ok()?;
    let src_root = PathBuf::from(home).join(".cargo/registry/src");
    let entries = fs::read_dir(&src_root).ok()?;
    let crate_dir = format!("rmk-{rmk_version}");
    let rel = Path::new(&crate_dir).join(rel_path);

    for entry in entries.flatten() {
        let candidate = entry.path().join(&rel);
        if candidate.is_file() {
            return Some(candidate);
        }
    }
    None
}

/// Replace `rmk-0.8.2/src/ble/battery_service.rs` wholesale with a kobu-flavoured
/// version that:
///
/// 1. Adds the BAS 1.1 `Battery Level Status` characteristic (UUID `0x2BED`)
///    next to the legacy Battery Level so hosts that understand BAS 1.1 (macOS
///    Sequoia, iOS 17+) can render a charging icon next to the kobu's
///    percentage.
/// 2. Rewrites `BleBatteryServer::run` to push a sentinel value immediately
///    on connect (macOS won't surface a BAS reading of 0%), drop the upstream
///    keypress gate, and heartbeat both characteristics every ~10s so VBUS
///    plug/unplug events get reflected in the Bluetooth menu without waiting
///    for the user to type a key.
/// 3. Polls VBUS via `embassy_nrf::pac::POWER.usbregstatus().vbusdetect()` on
///    every loop iteration — kobu's central is the only place that knows the
///    USB-power state, and we don't want to pipe a separate signal through
///    just for this.
///
/// We replace the entire upstream `battery_service.rs` body because the
/// changes touch the `BatteryService` struct, the `BleBatteryServer` type,
/// the constructor, and the run loop simultaneously — a fragile multi-hunk
/// find/replace would force us to re-tune every time we tweak one piece.
fn patch_rmk_battery_service() {
    // Increment the version suffix every time the embedded payload changes.
    const MARKER: &str = "// kobu: battery_service v3 (BAS 1.1 + VBUS charging) applied";
    // Sentinel that must be present in upstream rmk-0.8.2 — if missing, the
    // crate has been reorganised and our overwrite would land on the wrong
    // file.
    const UPSTREAM_SENTINEL: &str = "use crate::input_device::battery::{BATTERY_UPDATE, BatteryState};";
    const RMK_VERSION: &str = "0.8.2";

    let Some(path) = find_rmk_file(RMK_VERSION, "src/ble/battery_service.rs") else {
        println!(
            "cargo:warning=kobu: could not find rmk-{RMK_VERSION} battery_service.rs; \
             v3 patch was not applied"
        );
        return;
    };

    println!("cargo:rerun-if-changed={}", path.display());

    let existing = fs::read_to_string(&path).unwrap_or_else(|e| {
        panic!("kobu: failed to read {}: {e}", path.display());
    });

    if existing.contains(MARKER) {
        return;
    }

    if !existing.contains(UPSTREAM_SENTINEL) {
        panic!(
            "kobu: expected rmk-{RMK_VERSION} battery_service.rs sentinel missing in {}; \
             upstream may have changed — update firmware/build.rs",
            path.display()
        );
    }

    let new_contents = r##"use embassy_time::Timer;
use trouble_host::prelude::*;

use super::ble_server::Server;
use crate::input_device::battery::{BATTERY_UPDATE, BatteryState};

/// Battery service — kobu v3 layout. Includes both the classic BAS 1.0
/// Battery Level (0x2A19) characteristic and the BAS 1.1 Battery Level
/// Status (0x2BED) characteristic so hosts that understand BAS 1.1 can
/// surface a charging icon alongside the percentage.
#[gatt_service(uuid = service::BATTERY)]
pub(crate) struct BatteryService {
    /// Battery Level — u8 percentage 0..=100.
    #[descriptor(uuid = descriptors::VALID_RANGE, read, value = [0, 100])]
    #[characteristic(uuid = characteristic::BATTERY_LEVEL, read, notify)]
    pub(crate) level: u8,

    /// Battery Level Status (BAS 1.1) — 3-byte payload.
    ///
    /// Byte 0: `flags` — kobu always sends 0 (no optional fields present;
    /// the battery level is carried by the legacy 0x2A19 characteristic
    /// rather than the BAS 1.1 in-band copy).
    ///
    /// Bytes 1..3: `power_state` as a little-endian u16 with the standard
    /// BAS 1.1 bit layout:
    ///
    ///   * bit 0      = battery present (always 1 — kobu has a LiPo).
    ///   * bits 1..2  = wired external power source. 00 = absent, 01 =
    ///                  present. We set 01 when VBUS is detected (USB
    ///                  plugged in).
    ///   * bits 3..4  = wireless external power source. Always 00.
    ///   * bits 5..6  = battery charge state. 00 = unknown,
    ///                  01 = charging, 10 = discharging-active,
    ///                  11 = discharging-inactive. kobu emits 01 when
    ///                  VBUS is present and 10 otherwise.
    ///   * bits 7..15 = unused / reserved bits — left zero.
    #[characteristic(uuid = characteristic::BATTERY_LEVEL_STATUS, read, notify)]
    pub(crate) level_status: [u8; 3],
}

pub(crate) struct BleBatteryServer<'stack, 'server, 'conn, P: PacketPool> {
    pub(crate) battery_level: Characteristic<u8>,
    pub(crate) battery_level_status: Characteristic<[u8; 3]>,
    pub(crate) conn: &'conn GattConnection<'stack, 'server, P>,
}

impl<'stack, 'server, 'conn, P: PacketPool> BleBatteryServer<'stack, 'server, 'conn, P> {
    pub(crate) fn new(server: &Server, conn: &'conn GattConnection<'stack, 'server, P>) -> Self {
        Self {
            battery_level: server.battery_service.level,
            battery_level_status: server.battery_service.level_status,
            conn,
        }
    }
}

impl<P: PacketPool> BleBatteryServer<'_, '_, '_, P> {
    pub(crate) async fn run(&mut self) {
        // Wait 2 seconds, ensure that gatt server has been started.
        Timer::after_secs(2).await;

        // Sentinel 73% on connect: macOS suppresses BAS readings of 0% so a
        // fresh GATT cache that has never been populated stays blank. By
        // pushing a non-zero distinguishable value immediately we coax the
        // menu into showing *something*; the heartbeat below overwrites it
        // with the real level as soon as BatteryProcessor has it.
        let mut last_level: u8 = 73;
        if let Some(BatteryState::Normal(level)) = BATTERY_UPDATE.try_take() {
            last_level = level.max(1);
        }
        if let Err(e) = self.battery_level.notify(self.conn, &last_level).await {
            error!("Failed to notify battery level (kobu initial): {:?}", e);
        }

        // Initial Battery Level Status push — same idea: get a real value into
        // the cached characteristic before macOS reads it.
        let mut last_charging = kobu_vbus_present();
        let status_bytes = kobu_encode_level_status(last_charging);
        if let Err(e) = self.battery_level_status.notify(self.conn, &status_bytes).await {
            error!("Failed to notify level status (kobu initial): {:?}", e);
        }

        loop {
            // Wake every 10 s (or sooner if BATTERY_UPDATE fires) so VBUS
            // plug/unplug shows up in the Bluetooth menu within ~10 s and the
            // host's cached characteristic value never drifts stale.
            let next = embassy_time::with_timeout(
                embassy_time::Duration::from_secs(10),
                BATTERY_UPDATE.wait(),
            )
            .await;
            if let Ok(BatteryState::Normal(level)) = next {
                last_level = level.max(1);
            }
            if let Err(e) = self.battery_level.notify(self.conn, &last_level).await {
                error!("Failed to notify battery level: {:?}", e);
            }

            let charging_now = kobu_vbus_present();
            last_charging = charging_now;
            let status_bytes = kobu_encode_level_status(last_charging);
            if let Err(e) = self.battery_level_status.notify(self.conn, &status_bytes).await {
                error!("Failed to notify level status: {:?}", e);
            }
        }
    }
}

/// True when the nRF52840's POWER peripheral reports VBUS present. Mirrors
/// `crate::status_led::vbus_present` in the kobu firmware so the BAS notify
/// loop can stay self-contained (no extra signal plumbing).
#[cfg(feature = "_nrf_ble")]
fn kobu_vbus_present() -> bool {
    embassy_nrf::pac::POWER.usbregstatus().read().vbusdetect()
}

#[cfg(not(feature = "_nrf_ble"))]
fn kobu_vbus_present() -> bool {
    false
}

/// Encode the BAS 1.1 Battery Level Status payload. See the doc comment on
/// `BatteryService::level_status` for the bit layout.
fn kobu_encode_level_status(charging: bool) -> [u8; 3] {
    // Battery is always present on kobu (bit 0 = 1).
    let mut power_state: u16 = 0b0000_0001;
    if charging {
        // bits 1..2 = 01 (wired external power present).
        power_state |= 0b0000_0010;
        // bits 5..6 = 01 (charging).
        power_state |= 0b0010_0000;
    } else {
        // bits 5..6 = 10 (discharging-active).
        power_state |= 0b0100_0000;
    }
    [0x00, (power_state & 0xff) as u8, ((power_state >> 8) & 0xff) as u8]
}

"##;

    let mut out = String::from(new_contents);
    out.push_str(MARKER);
    out.push('\n');

    fs::write(&path, out).unwrap_or_else(|e| {
        panic!("kobu: failed to write {}: {e}", path.display());
    });
}
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

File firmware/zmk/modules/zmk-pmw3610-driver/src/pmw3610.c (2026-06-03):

/*
 * Copyright (c) 2022 The ZMK Contributors
 *
 * SPDX-License-Identifier: MIT
 */

#define DT_DRV_COMPAT pixart_pmw3610

#include <zephyr/kernel.h>
#include <zephyr/sys/byteorder.h>
#include <zephyr/input/input.h>
#include <zephyr/pm/device.h>
#include <zmk/keymap.h>
#include <zmk/events/activity_state_changed.h>
#include "pmw3610.h"

#include <zephyr/logging/log.h>
LOG_MODULE_REGISTER(pmw3610, CONFIG_PMW3610_LOG_LEVEL);

//////// Sensor initialization steps definition //////////
// init is done in non-blocking manner (i.e., async), a //
// delayable work is defined for this purpose           //
enum pmw3610_init_step {
    ASYNC_INIT_STEP_POWER_UP,  // reset cs line and assert power-up reset
    ASYNC_INIT_STEP_CLEAR_OB1, // clear observation1 register for self-test check
    ASYNC_INIT_STEP_CHECK_OB1, // check the value of observation1 register after self-test check
    ASYNC_INIT_STEP_CONFIGURE, // set other registes like cpi and donwshift time (run, rest1, rest2)
                               // and clear motion registers

    ASYNC_INIT_STEP_COUNT // end flag
};

/* Timings (in ms) needed in between steps to allow each step finishes succussfully. */
// - Since MCU is not involved in the sensor init process, i is allowed to do other tasks.
//   Thus, k_sleep or delayed schedule can be used.
static const int32_t async_init_delay[ASYNC_INIT_STEP_COUNT] = {
    [ASYNC_INIT_STEP_POWER_UP] = 10 + CONFIG_PMW3610_INIT_POWER_UP_EXTRA_DELAY_MS, // >10ms needed
    [ASYNC_INIT_STEP_CLEAR_OB1] = 200, // 150 us required, test shows too short,
                                       // also power-up reset is added in this step, thus using 50 ms
    [ASYNC_INIT_STEP_CHECK_OB1] = 50,  // 10 ms required in spec,
                                       // test shows too short,
                                       // especially when integrated with display,
                                       // > 50ms is needed
    [ASYNC_INIT_STEP_CONFIGURE] = 0,
};

// kobu: bounded restart-from-scratch retries when the flaky 3-wire SPI read
// makes the self-test/product-id step fail at power-up (see pmw3610_async_init).
#define PMW3610_INIT_MAX_RETRIES   100
#define PMW3610_INIT_RETRY_DELAY_MS 50

static int pmw3610_async_init_power_up(const struct device *dev);
static int pmw3610_async_init_clear_ob1(const struct device *dev);
static int pmw3610_async_init_check_ob1(const struct device *dev);
static int pmw3610_async_init_configure(const struct device *dev);

static int (*const async_init_fn[ASYNC_INIT_STEP_COUNT])(const struct device *dev) = {
    [ASYNC_INIT_STEP_POWER_UP] = pmw3610_async_init_power_up,
    [ASYNC_INIT_STEP_CLEAR_OB1] = pmw3610_async_init_clear_ob1,
    [ASYNC_INIT_STEP_CHECK_OB1] = pmw3610_async_init_check_ob1,
    [ASYNC_INIT_STEP_CONFIGURE] = pmw3610_async_init_configure,
};

//////// Function definitions //////////

static int pmw3610_read(const struct device *dev, uint8_t addr, uint8_t *value, uint8_t len) {
	const struct pixart_config *cfg = dev->config;
	const struct spi_buf tx_buf = { .buf = &addr, .len = sizeof(addr) };
	const struct spi_buf_set tx = { .buffers = &tx_buf, .count = 1 };
	struct spi_buf rx_buf[] = {
		{ .buf = NULL, .len = sizeof(addr), },
		{ .buf = value, .len = len, },
	};
	const struct spi_buf_set rx = { .buffers = rx_buf, .count = ARRAY_SIZE(rx_buf) };
	return spi_transceive_dt(&cfg->spi, &tx, &rx);
}

static int pmw3610_read_reg(const struct device *dev, uint8_t addr, uint8_t *value) {
	return pmw3610_read(dev, addr, value, 1);
}

static int pmw3610_write_reg(const struct device *dev, uint8_t addr, uint8_t value) {
	const struct pixart_config *cfg = dev->config;
	uint8_t write_buf[] = {addr | SPI_WRITE_BIT, value};
	const struct spi_buf tx_buf = { .buf = write_buf, .len = sizeof(write_buf), };
	const struct spi_buf_set tx = { .buffers = &tx_buf, .count = 1, };
	return spi_write_dt(&cfg->spi, &tx);
}

static int pmw3610_write(const struct device *dev, uint8_t reg, uint8_t val) {
	pmw3610_write_reg(dev, PMW3610_REG_SPI_CLK_ON_REQ, PMW3610_SPI_CLOCK_CMD_ENABLE);
	k_sleep(K_USEC(T_CLOCK_ON_DELAY_US));

    int err = pmw3610_write_reg(dev, reg, val);
    if (unlikely(err != 0)) {
        return err;
    }
    
    pmw3610_write_reg(dev, PMW3610_REG_SPI_CLK_ON_REQ, PMW3610_SPI_CLOCK_CMD_DISABLE);
    return 0;
}

static int pmw3610_set_cpi(const struct device *dev, uint32_t cpi, 
                           bool swap_xy, bool inv_x, bool inv_y) {
    /* Set resolution with CPI step of 200 cpi
     * 0x1: 200 cpi (minimum cpi)
     * 0x2: 400 cpi
     * 0x3: 600 cpi
     * :
     */

    if ((cpi > PMW3610_MAX_CPI) || (cpi < PMW3610_MIN_CPI)) {
        LOG_ERR("CPI value %u out of range", cpi);
        return -EINVAL;
    }

    uint8_t value = 0x00;
    int err = 0;

    LOG_INF("Setting cpi: %d", cpi);
    // Convert CPI to register value
    // Set prefered RES_STEP
    //   BIT 4-0: CPI
    uint8_t cpi_val = cpi / 200;
    value = (value & 0xE0) | (cpi_val & 0x1F);

    // Convert axis to register value
    // Set prefered RES_STEP
    //   BIT 7: SWAP_XY
    //   BIT 6: INV_X
    //   BIT 5: INV_Y
    LOG_INF("Setting axis swap_xy: %s inv_x: %s inv_y: %s", 
            swap_xy ? "yes" : "no", inv_x ? "yes" : "no", inv_y ? "yes" : "no");

#if IS_ENABLED(CONFIG_PMW3610_SWAP_XY)
    value |= (1 << 7);
#else
    if (swap_xy) { value |= (1 << 7); } else { value &= ~(1 << 7); }
#endif
#if IS_ENABLED(CONFIG_PMW3610_INVERT_X)
    value |= (1 << 6);
#else
    if (inv_x) { value |= (1 << 6); } else { value &= ~(1 << 6); }
#endif
#if IS_ENABLED(CONFIG_PMW3610_INVERT_Y)
    value |= (1 << 5);
#else
    if (inv_y) { value |= (1 << 5); } else { value &= ~(1 << 5); }
#endif

    LOG_INF("Setting CPI to %u (reg value 0x%x)", cpi, value);

    /* set the cpi */
    uint8_t addr[] = {0x7F, PMW3610_REG_RES_STEP, 0x7F};
    uint8_t data[] = {0xFF, value,                0x00};

	pmw3610_write_reg(dev, PMW3610_REG_SPI_CLK_ON_REQ, PMW3610_SPI_CLOCK_CMD_ENABLE);
	k_sleep(K_USEC(T_CLOCK_ON_DELAY_US));

    /* Write data */
    for (size_t i = 0; i < sizeof(data); i++) {
        err = pmw3610_write_reg(dev, addr[i], data[i]);
        if (err) {
            LOG_ERR("Burst write failed on SPI write (data)");
            break;
        }
    }
    pmw3610_write_reg(dev, PMW3610_REG_SPI_CLK_ON_REQ, PMW3610_SPI_CLOCK_CMD_DISABLE);

    if (err) {
        LOG_ERR("Failed to set CPI");
        return err;
    }

    return 0;
}
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

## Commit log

2026-05-06 chore: drop ZMK firmware build artifacts in favor of RMK
    This repo has migrated to RMK for firmware (see firmware/ directory and
    .github/workflows/firmware.yml). The ZMK user-config, Docker build
    scripts, GitHub Actions workflow, and related Makefile/build.yaml are
    no longer maintained, so remove them to avoid confusion and reduce noise.
    - Delete config/ (ZMK keymap, shield definitions, west.yml, zephyr module)
    - Delete scripts/zmk-build.sh and the now-empty scripts/ directory
    - Delete Makefile (every target was ZMK-specific)
    - Delete build.yaml (ZMK build matrix)
    - Delete .github/workflows/firmware-zmk.yml
    - README.md: drop the "ZMK ファームウェア (ローカルビルド)" section
    -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
2026-05-10 feat(firmware): hand-rolled BidirectionalMatrix build for mixed diodes
    Drop the [#rmk_central] / [#rmk_peripheral] macros and implement the
    two binaries directly using rmk::matrix::bidirectional_matrix. The
    assembled boards have main-unit diodes flipped (anode-on-/COL,
    col2row-friendly) while thumb-unit diodes are correct
    (anode-on-/ROW, row2col-friendly), which a single Matrix<...,
    COL2ROW> cannot serve. BidirectionalMatrix's per-cell scan_map lets
    each key drive whichever side holds its anode and read the cathode
    side, so the same physical 9-pin matrix now scans both halves of the
    keymap at once.
    Layout:
    - 9 Flex pins per half: 4 row pins (D3..D6) + 5 col pins. The col
    pin order is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
2026-05-10 fix(firmware): initialize all Flex pins as pull-down input before scanning
    Reproduction: with the BidirectionalMatrix build, every key was dead
    even though both halves enumerated. Root cause is that Flex::new leaves
    the pin in DISCONNECTED mode (no drive, no pull). The BidirectionalMatrix
    scan loop only flips a pin to input mode after using it as output once
    (at the end of the cell), so any pin that is *only ever* an in_pin
    under our scan_map -- ROW0..ROW2 in the LEFT/RIGHT main rows, and the
    COL pins for thumb cells on row 3 -- never enters input mode and
    is_high() reads garbage forever.
    Fix: explicitly call `pin.set_as_input(Pull::Down)` on every entry of
    the Flex array before handing it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
2026-05-11 fix(firmware): keep left thumb inner-to-outer = A B C D after col_pins reversal
    Reversing the left col_pins for canonical QWERTY mapping also reversed
    the physical-to-keymap mapping for the left thumb cluster. With the
    previous diagnostic row 3 = [No, A, B, C, D, ...] the innermost
    thumb (SW2 at /COL0 wire) ended up at keymap col 4 = "D", and the
    outermost (SW5 at /COL3 wire) at col 1 = "A". User expected "inner
    to outer = A B C D" (matching the pre-reversal convention they had
    been testing against), so reading "D" on the innermost felt like the
    key had stopped working.
    Reverse the left-thumb portion of row 3 so the inner thumb is "A"
    again:
    [No, D, C, B, A, E, F, G, H, No]
    The right th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
2026-05-13 feat(firmware): enable LEFT-half trackball (PMW3610) on central
    Adds the central-side PMW3610 input_device block with the pin map from
    the schematic header (SDIO=P0_02, SCLK=P0_03, NCS=P0_09, MOTION=P0_28).
    The MOTION pin is intentionally omitted from the toml so the driver
    polls continuously instead of gating on the active-low IRQ; combined
    with force_awake = true this keeps the sensor responsive even before
    the IRQ wiring is verified. Uses the stock Pmw3610Processor (mouse
    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
2026-05-15 docs: document Vial keymap-editor workflow (#17)
    * docs: document Vial keymap-editor workflow
    Add a "Vial でキーマップを編集する" section to README covering:
    * the USB-only constraint and which browsers work
    * connection steps via vial.rocks
    * the [[0,0],[0,9]] unlock chord — explained as matrix positions, not
    logical keycodes, since the distinction trips people up
    * layer 3's User0..User7 → BT0..BT3/Next/Prev/Clear/Switch table that
    agrees with what RMK 0.8 actually does given ble_profiles_num = 4
    * the factory-reset clear_layout / clear_storage flow
    * known limitations: no BLE-side editing, peripheral half is not a
    Vial endpoint, and a pointer to upstream tracking is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
2026-05-16 chore: bump Node to 26.1.0 via flake.nix (#45)
    * chore: bump Node to 26.1.0 via flake.nix
    nodejs_26 hasn't landed in nixos-unstable yet (2026-05-16). It is
    available on the staging-next branch, so add a second nixpkgs input
    pointing there and route only `nodejs_26` through it — everything
    else (Rust, probe-rs, flip-link, etc.) stays on the stable
    nixos-unstable channel.
    flake.nix:
    * New `nixpkgs-node` input pinned to staging-next
    (currently 1ec6a89 / 2026-05-15, ships nodejs 26.1.0).
    * `nodejs = pkgsNode.nodejs_26` while `pkgs` (everything else)
    remains on the unstable channel.
    * Comment explicitly notes this is a temporary detour — when
    nodejs_26 reaches unstable the second inpu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
2026-05-17 feat(firmware): port KobitoKey_QWERTY keymap to kobu (7 layers, combos, hold-taps)
    KobitoKey_QWERTY (ZMK) のキーマップを kobu (RMK 0.8) に 1:1 移植。
    親指クラスターを実機検証して以下の最終形に落ち着いた:
    LEFT (XIAO直下 → 外側): 英数/Shift, Ctrl, BS/Cmd, BS
    RIGHT (XIAO直下 → 外側): Esc/Alt, Space/LT(2), Enter/LT(3), BS
    主な変更:
    - layers 4 → 7 (Mac default / Win-Linux overlay / 数字 / 設定+BLE / マウス /
    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
2026-05-19 feat(web/ui): add categorised keycode picker (#31)
    Modal palette that opens when a cell is selected on the keymap. Tabs
    cover basic / mods / special / function / media / system / mouse /
    layer / user / other, plus a "tap/hold" tab that builds the parametric
    encodings (MO / TO / TG / DF / OSL / OSM / LT / MT / WM / LM) with a
    modifier-bit picker and a base-key dropdown.
    Search filters across name, label, description, and aliases (with both
    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
2026-05-19 feat(web/ui): add Layer 3 Bluetooth control panel (#32)
    Layer 3 is kobu's BLE control layer (User0..User3 = pick BT profile
    0..3, User4/5 = next/prev BT, User6 = clear bond, User7 = switch
    output). The panel walks layer 3 looking for User keycodes, then
    renders one card per BLE profile and one per BLE control with the
    matrix location and a "locate on keymap" button.
    Until phase 6 lands the matching Custom Vial commands in firmware the
    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
2026-05-19 feat(web): mount phase 3 editor and translate UI to Japanese
    App now renders the Editor section once the connection store reaches
    ready, sharing the page with the existing connect panel. Header,
    connect prompts, error recovery hints, status badges, and the
    ConnectButton test assertion are translated to Japanese — canonical
    RMK keycode names (A, LCtrl, MediaPlayPause, …) and SVG short labels
    stay as-is so firmware identifiers and English search keywords keep
    working.
2026-05-19 feat(case): add main-unit spacer plates and refresh plate exports
    New three-piece spacer stack (top + bottom1 + bottom2) for both
    main-unit halves, sized to bridge the gap between the PCB stand-offs
    and the case bottom plate so the XIAO BLE and FFC connector sit at
    their intended z-height.
    Plate STL exports (main-bottom / main-side / thumb-bottom / thumb-side)
    are re-exported in the same pass so the case files stay consistent
    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
    [main-bottom-plate.stl, main-side-plate.stl, main-unit-left-spacer-bottom1.stl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]
2026-05-20 feat(web/protocol): add BootloaderJump command and enterBootloader helper
    `buildBootloaderJump()` wraps the Via 0x0b reboot-to-UF2 command. The
    `enterBootloader(transport)` helper sends it and treats the inevitable
    post-reboot transport errors (receive-timeout / send-failed /
    disconnected) as success — the firmware can't ack the command before
    it reboots, and the HID endpoint vanishes immediately afterwards.
    Used by the firmware install UI so users with a connected kobu can
    jump the central into UF2 mode without reaching for the RESET button.
2026-05-20 test(web/ui): cover connect / status / toolbar components
    ConnectionStatus.tsx (new):
    * One assertion per state-machine branch (unsupported / idle /
    connecting / ready / wrong-device / error), including the (キャッシュ)
    suffix and the tooltip content.
    ConnectButton.tsx (expanded from one smoke test):
    * idle button label + click invokes promptConnect
    * connecting label + disabled
    * ready panel with disconnect callback + cache indicator
    * wrong-device panel with UID + disconnect callback
    * parametric recovery-hint coverage for each errorKind
    * generic error path + clearError on click
    EditorToolbar.tsx (new):
    * renders nothing pre-attach
    * one tab per layer, aria-selected on active,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
2026-05-20 test(web/ui): cover picker, BT panel, firmware section and editor shell
    KeycodePicker.tsx (new):
    * dialog renders with current keycode label
    * default Basic catalogue picks "A" (0x04)
    * tab switch shows the right category
    * search filters across categories (including Japanese alias hit:
    "ひらがな" → International2)
    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
2026-05-20 feat(web/install): wrap File System Access API for UF2 writes
    Two thin modules used by the new install flow:
    * `install/filesystem.ts` — isFileSystemAccessSupported gate,
    pickXiaoBoot wraps showDirectoryPicker with named error mapping
    (AbortError → picker-cancelled, NotAllowedError → permission-denied),
    verifyXiaoBootDirectory probes for INFO_UF2.TXT so we can warn when
    the user picks the wrong folder, writeUf2 writes the bytes and
    treats post-write disconnect (InvalidStateError / NotFoundError /
    NetworkError) as success since the Adafruit UF2 bootloader reboots
    the device as soon as it consumes the file.
    * `install/install.ts` — fetchUf2 pulls the release asset and w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
2026-05-20 fix(web): proxy github.com release downloads through dev server
    GitHub release URLs (github.com → release-assets.githubusercontent.com)
    don't return Access-Control-Allow-Origin, so a direct browser fetch
    to download the uf2 fails with "Failed to fetch" (CORS preflight on
    the redirect target). Verified in Chrome DevTools:
    * mode: 'no-cors' → opaque response (server reachable)
    * mode: 'cors' → TypeError "Failed to fetch"
    In dev mode, vite now proxies `/__release/*` to `https://github.com/*`
    with `followRedirects: true`, so the install flow rewrites the asset
    URL to a same-origin path and the bytes come back through the dev
    server with no CORS check in the browser.
    `rewriteFor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
2026-05-20 fix(web/connect): revoke device authorization on 切断 so reload stays disconnected
    The previous fix made the「切断」button work within a single page
    load, but reloading brought the user back to the connected state:
    the silent-reconnect on mount calls navigator.hid.getDevices(),
    which still listed the previously-authorised kobu, and we attached.
    Call `device.forget()` after closing the transport. This revokes the
    page's permission for that specific device, so getDevices() no
    longer returns it; silent reconnect on the next page load finds an
    empty list and the user stays in idle. Reconnecting requires the
    explicit「kobu に接続」click + device picker.
    Older or polyfilled HIDDevice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
2026-05-20 test(web/ui): lock in thumb-row alignment for the post-fix vial.json
    A regression test that runs `buildCells` against the production
    layout from `firmware/vial.json` (post commit 4a21152, with
    `{x:1}` indent + `{x:1}` midline gap on the thumb row) and asserts
    that every left-half thumb (3,1)..(3,4) lands at the same x as
    its same-col letter (0,1)..(0,4), and every right-half thumb
    (3,5)..(3,8) lands at the same x as (0,5)..(0,8).
    This proves the renderer is correct against the shipped layout; the
    remaining failure mode is purely "user's device still runs an older
    firmware that embeds the pre-fix vial.json". When they reflash with
    the latest central.uf2 the connection store's new cache-misma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
2026-05-23 feat(web): deploy + user docs (Phase 5.3, closes #38) (#51)
    * docs(web): user guide + FAQ + production deploy + CSP (#38)
    ### Cloudflare Workers production deploy
    - New `deploy` job in `.github/workflows/web.yml` runs after `ci`
    succeeds on `main`. Requires two repo secrets:
    `CLOUDFLARE_API_TOKEN` and `CLOUDFLARE_ACCOUNT_ID` (notes in the
    workflow file).
    - Skips on PRs — preview deployments would need a separate wrangler
    env + routing rules and are deferred.
    ### CSP + security headers (worker/index.ts)
    - `Content-Security-Policy: default-src 'self'; script-src 'self'; ...`
    with the minimum opt-ins needed (Tailwind / SVG keymap renderer
    use inline `style=""` → `style-src 'un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
2026-05-24 fix(firmware): invert Y on peripheral pointer
    The right-half PMW3610 is mirrored relative to the left-half mount,
    which left Y inverted by default — moving the finger up sent the
    cursor down. Negate y in PointerProcessor so finger-up matches
    cursor-up. X already matched physical direction so it stays as-is.
2026-05-25 chore: add case
    [reset-button.stl, thumb-bottom-plate.stl, thumb-side-plate.stl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]
2026-06-01 feat(firmware): keyboard.toml — keymap, power topology, dynamic-LED pins
    Three configuration changes:
    - Keymap: shift the layer-0 thumb cluster outward on both halves so the
    innermost (XIAO直下) thumb is plain Backspace; the 直下-adjacent left thumb
    is MT(Language1, LShift) (tap=かな / hold=LShift). Layer-2 かな/Shift moved
    col4→col3 to sit under the same physical thumb as the base layer.
    - Power: dcdc_reg0 = false (was true). The XIAO nRF52840 BLE is NORMAL-voltage
    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
2026-06-01 chore: caseデータを調整
    [hinji-cover.stl, main-bottom-plate.stl, main-side-plate.stl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]
2026-06-02 fix(firmware/ble): rmk patches — request-once host conn, 8ms PMW3610 poll, diag counter
    Idempotent in-place patches to the rmk-0.8.2 registry source:
    - Host conn-params: request the KobitoKey range [7.5,15ms]/latency-0 ONCE
    and stop the periodic 2s re-assert. The re-assert churn re-opened
    negotiation and made macOS power-relax the link → intermittent のろのろ
    that recovered in ~5s (the re-assert cycle).
    - PMW3610 poll 2ms→8ms (match ZMK CONFIG_PMW3610_REPORT_INTERVAL_MIN; stop
    over-feeding the 7.5ms split link).
    - KOBU_PERIPHERAL_SAMPLES counter in read_event for the on-device
    split-/production-rate LED diagnostic.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
    [build.rs]
2026-06-02 refactor(firmware): relocate RMK firmware into firmware/rmk/
    Move the RMK firmware (Cargo project, keyboard.toml, src/, build.rs,
    keymap/, scripts/, vial.json, memory.x, .cargo/, rust-toolchain.toml)
    from firmware/ into firmware/rmk/, so firmware/ now holds rmk/ alongside
    the new zmk/ port. RMK contents are unchanged except the wiring intrinsic
    to the move:
    - firmware/rmk/.envrc: the root flake is now two levels up
    (use flake "path:../..#firmware", watch ../../flake.{nix,lock}).
    - scripts/lint_keymap_config.py: resolve vial.json / keyboard.toml via
    the rmk root (parents[1]) instead of <repo-root>/firmware.
    [build.rs]
2026-06-02 build(firmware/zmk): add west manifest, zephyr module, build matrix
    config/west.yml pins ZMK v0.3 + badjeff pmw3610 (zmk-0.3) + caksoylar rgbled-widget (v0.3). zephyr/module.yml (board_root: config) makes the kobu shield discoverable by zmk-nix. build.yaml is GitHub 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
2026-06-03 fix(firmware/zmk/trackball): KobitoKey-style pure-IRQ scroll @500 kHz
    The LEFT scroll ball worked for FAST rolls but ignored SLOW ones, and was
    unreliable per boot. Root cause: kobu was POLLING the sensor (a kobu-added
    patch) while KobitoKey — same badjeff driver — is IRQ-driven. Polling
    read+cleared the motion register every 10 ms, destroying the sub-count
    accumulation of slow rolls; and the poll patch existed only because the
    MOTION/P0_28 IRQ "never fired" — which was really the flaky-SPI init FAILING
    (the driver arms the IRQ only after a successful init, now guaranteed by the
    init-retry). Switch the LEFT half to pure IRQ (CONFIG_PMW3610_POLL_INTERVAL_MS=0)
    like KobitoKey: slow + fas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
    [pmw3610.c]
2026-06-03 feat(firmware/zmk): disable deep sleep on both halves
    Per user (battery is not a concern): keep the board and trackballs always
    responsive. CONFIG_ZMK_SLEEP=n on central + peripheral; the PMW3610s are also
    held out of rest modes by `force-awake`, so the balls never have to wake up.
2026-06-04 feat(zmk-editor): live keymap editor UI
    Connect (USB/BLE) + status, the keyboard grid rendered from the device's
    physical layout, layer tabs with management + save/discard/undo/redo, and
    the behavior picker (keycode palette + modifier toggles, layer / named-
    constant / range params driven by device behavior metadata).
2026-06-04 feat(firmware): parameterised ZMK build for the editor's detailed settings
    firmware.yml gains optional workflow_dispatch inputs (overrides_b64 +
    build_id echoed into run-name); a new step decodes them and runs
    scripts/zmk-apply-overrides.py, which patches the kobu devicetree/keymap
    (CPI, scalers, tapping-term, combo timeout, auto-mouse timeout) before the
    nix build. Custom builds don't overwrite the rolling firmware-latest
    release. No-op for normal push/PR builds.
2026-06-04 Revert "trackball tuning" (HW regression) — restore proven-good firmware
    Reverts the 4 commits 27df3ec..083682e (PMW3610 force-awake heartbeat,
    scroll divisor 18->12, the editor require-prior-idle knob, and the rebuilt
    kobu_left.uf2). They regressed on real hardware. This returns firmware,
    config, editor, and the kobu_left.uf2 to the state at 0b10127.
    [pmw3610.c]
2026-06-04 build(firmware/zmk): rebuild kobu_left.uf2 (250kHz LEFT SPI)
    The exact binary the user bench-tested. Right/reset unchanged.
2026-06-05 feat(firmware/zmk): LEFT ball scrolls in any direction (2D scroll)
    Replace the horizontal-roll-only scroll mapping with the stock
    zip_xy_to_scroll_mapper: up/down roll -> vertical wheel, left/right roll ->
    horizontal wheel. Rolling the ball any direction now scrolls that way, and
    "scroll up" is just "roll up" (the previous scheme made up-scroll a sideways
    motion, which the user found awkward). Keeps the ~18 raw-counts/line scaler
    and the 250 kHz SPI. Direction is the best-guess natural sign (roll-up =
    scroll-up, roll-right = scroll-right) from the old known WHEEL+ = scroll-up;
    a single &zip_scroll_transform INPUT_TRANSFORM_{Y,X}_INVERT flips it if a
    half reads reversed.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
